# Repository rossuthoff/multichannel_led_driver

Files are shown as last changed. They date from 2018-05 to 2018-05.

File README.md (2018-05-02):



# multichannel_led_driver
Switching boost LED driver based on the Linear Technology [LT3478-1](http://www.analog.com/en/products/power-management/led-driver-ic/buck-boost-led-drivers/lt3478.html) chip.

## related repositories
This design requires the footprints found in the [kicad_footprints](https://github.com/rossuthoff/kicad_footprints) repository. Make sure the library and .mod files are added to your folder search locations. This board utilizes the [ytai/IOIO](https://github.com/ytai/ioio) microcontroller (MCU) and is designed to match to its header layout. Other microcontrollers that can send 3.3 V signals and control an I2C interface may be used. 

## general use
### power supply
LED driver is used in boost mode. The battery voltage must be less than the voltage drop across each individual LED string. Header connnection between this board and the IOIO board provide power to the MCU.

### led strings
Connect the LED strings to V+ (anode) and V1 through V9 (cathodes) connections. The LED string to be illuminated is controlled through a 3.3V signal to the s1 through s9 pins. The applied current is controlled through a Analog Devices [AD5247](http://www.analog.com/en/products/digital-to-analog-converters/digital-potentiometers/ad5247.html) digital potentiometer with an I2C interface.

# references

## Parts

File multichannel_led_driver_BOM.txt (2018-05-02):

Reference	Locations	Value	Footprint	Notes	Manufacturer	PN	Distributor	Dist PN	Dist Link
C1	1	3.3uF	Capacitors_SMD:C_0603	25V	TDK Corporation	C1608X5R1E335K080AC	Digikey	445-14141-1-ND	https://www.digikey.com/product-detail/en/tdk-corporation/C1608X5R1E335K080AC/445-14141-1-ND/3955807
C2	1	4.7uF	Capacitors_SMD:C_1206	25V	TDK Corporation	C3216X5R1E475K160AA	Digikey	445-4047-2-ND	http://www.digikey.com/product-detail/en/tdk-corporation/C3216X5R1E475K160AA/445-4047-2-ND/1965635
C3	1	10uF	Capacitors_SMD:C_1812	25V	TDK Corporation	C4532X5R1E106M250KA	Digikey	445-3926-2-ND	http://www.digikey.com/product-detail/en/tdk-corporation/C4532X5R1E106M250KA/445-3926-2-ND/1923415
"C4, C6"	2	1uF	Capacitors_SMD:C_0603	25V	TDK Corporation	CGB3B1X5R1E105K055AC	Digikey	445-13224-2-ND	http://www.digikey.com/product-detail/en/tdk-corporation/CGB3B1X5R1E105K055AC/445-13224-2-ND/3950460
"C5, C7"	2	0.1uF	Capacitors_SMD:C_0603	25V	Kemet	C0603C104K3RACTU	Digikey	399-1281-1-ND	https://www.digikey.com/product-detail/en/kemet/C0603C104K3RACTU/399-1281-1-ND/416057
C8	1	10uF	Capacitors_Tantalum_SMD:CP_Tantalum_Case-A_EIA-3216-18_Reflow	10V	AVX Corporation	TPSA106K010R0900	Digikey	478-1751-1-ND	https://www.digikey.com/product-detail/en/avx-corporation/TPSA106K010R0900/478-1751-1-ND/564783
D1	1	D_Schottky_AAK	footprints:D_PowerDI-5		Diode Incorporated	PDS560-13	Digikey	PDS560DICT-ND	http://www.digikey.com/product-detail/en/diodes-incorporated/PDS560-13/PDS560DICT-ND/776779
D2	1	LED	footprints:LED_0603		Panasonic Electric Components	LNJ937W8CRA	Digikey	LNJ937W8CRATR-ND	http://www.digikey.com/product-detail/en/panasonic-electronic-components/LNJ937W8CRA/LNJ937W8CRACT-ND/2349027
J1	1	CONN_01X04	JST_PH_S4B-PH-SM4-TB_04x2.00mm_Angled		JST Sales America	S4B-PH-SM4-TB(LF)(SN)	Digikey	455-1751-2-ND	https://www.digikey.com/product-detail/en/jst-sales-america-inc/S4B-PH-SM4-TB-LF-SN/455-1751-2-ND/926657
J4	1	CONN_01X02	Connectors_JST:JST_PH_S2B-PH-SM4-TB_02x2.00mm_Angled		JST Sales America	S2B-PH-SM4-TB(LF)(SN)	Digikey	455-1749-2-ND	http://www.digikey.com/product-detail/en/jst-sales-america-inc/S2B-PH-SM4-TB(LF)(SN)/455-1749-2-ND/926655
L1	1	6.8uH	footprints:Sumida_L_CDRH105R		Sumida America Components	CDRH105RNP-6R8NC	Digikey	308-1927-2-ND	https://www.digikey.com/product-detail/en/sumida-america-components-inc/CDRH105RNP-6R8NC/308-1927-2-ND/3947171
P2	1	CONN_01X06	Connectors_JST:JST_PH_S6B-PH-SM4-TB_06x2.00mm_Angled		JST Sales America	S6B-PH-SM4-TB(LF)(SN)	Digikey	455-1753-2-ND	https://www.digikey.com/product-detail/en/jst-sales-america-inc/S6B-PH-SM4-TB-LF-SN/455-1753-2-ND/926659
"P3,P5,P9,P10,P11,P12,P13,P14,P15,P16"	10		Pin_Headers:Pin_Header_Straight_Pitch2.54mm	DNI					
"Q1,Q2,Q3,Q4,Q9,Q10,Q11,Q12,Q17"	9	Si2308CDS	TO_SOT_Packages_SMD:SOT-23		Vishay Siliconix	SI2308CDS-T1-GE3	Digikey	SI2308CDS-T1-GE3CT-ND	https://www.digikey.com/product-detail/en/vishay-siliconix/SI2308CDS-T1-GE3/SI2308CDS-T1-GE3CT-ND/7616363
"Q5,Q6,Q7,Q8,Q13,Q14,Q15,Q16,Q20"	9	Si2309CDS	TO_SOT_Packages_SMD:SOT-23		Vishay Siliconix	SI2309CDS-T1-GE3	Digikey	SI2309CDS-T1-GE3CT-ND	https://www.digikey.com/product-detail/en/vishay-siliconix/SI2309CDS-T1-GE3/SI2309CDS-T1-GE3CT-ND/3305365
R1	1	100k	Resistors_SMD:R_0402	1%	Yageo	RC0402FR-07100KL	Digikey	311-100KLRTR-ND	http://www.digikey.com/product-detail/en/yageo/RC0402FR-07100KL/311-100KLRTR-ND/726526
R2	1	24k	Resistors_SMD:R_0402	1%	Yageo	RC0402FR-0724KL	Digikey	311-24KLRTR-ND	http://www.digikey.com/product-detail/en/yageo/RC0402FR-0724KL/311-24KLRTR-ND/2827581
R3	1	69.8k	Resistors_SMD:R_0402	1%	Yageo	RC0402FR-0769K8L	Digikey	YAG3216TR-ND	http://www.digikey.com/product-detail/en/yageo/RC0402FR-0769K8L/YAG3216TR-ND/5281076
"R4, R5, R7, R8, R9, R10, R11, R12, R13, R14, R16"	11	10k	Resistors_SMD:R_0603	1%	Yageo	RC0603FR-0710KL	Digikey	311-10.0KHRTR-ND	https://www.digikey.com/product-detail/en/yageo/RC0603FR-0710KL/311-10.0KHRTR-ND/726880
R6	1	1k	Resistors_SMD:R_0603	1%	Yageo	RC0603FR-071KL	Digikey	311-1.00KHRTR-ND	https://www.digikey.com/product-detail/en/yageo/RC0603FR-071KL/311-1.00KHRTR-ND/726843
"R17,R19,R20,R21,R22,R23,R24,R25,R26,R27,R28,R29,R30,R31,R32,R33,R34,R35"	18	510	Resistors_SMD:R_0603	1%	Yageo	RC0603FR-07510RL	Digikey	311-510HRTR-ND	https://www.digikey.com/product-detail/en/yageo/RC0603FR-07510RL/311-510HRTR-ND/727285
SW1	1	SW_SPST	footprints:C&K_SPST_switch_L101011MS02Q		C&K	L101011MS02Q	Digikey	CKC5106-ND	http://www.digikey.com/product-detail/en/c-k/L101011MS02Q/CKC5106-ND/484142
U1	1	LT3478-1	footprints:TSSOP-16-1EP_4.4x5mm_Pitch0.65mm		Linear Technologies	LT3478EFE-1#PBF	Digikey	LT3478EFE-1#PBF-ND	http://www.digikey.com/product-detail/en/linear-technology/LT3478EFE-1-PBF/LT3478EFE-1-PBF-ND/1619965
U3	1	AD5247	footprints:SC-70-6		Analog Devices	AD5247BKSZ10-RL7	Digikey	AD5247BKSZ10-RL7CT-ND	https://www.digikey.com/product-detail/en/analog-devices-inc/AD5247BKSZ10-RL7/AD5247BKSZ10-RL7CT-ND/1140637

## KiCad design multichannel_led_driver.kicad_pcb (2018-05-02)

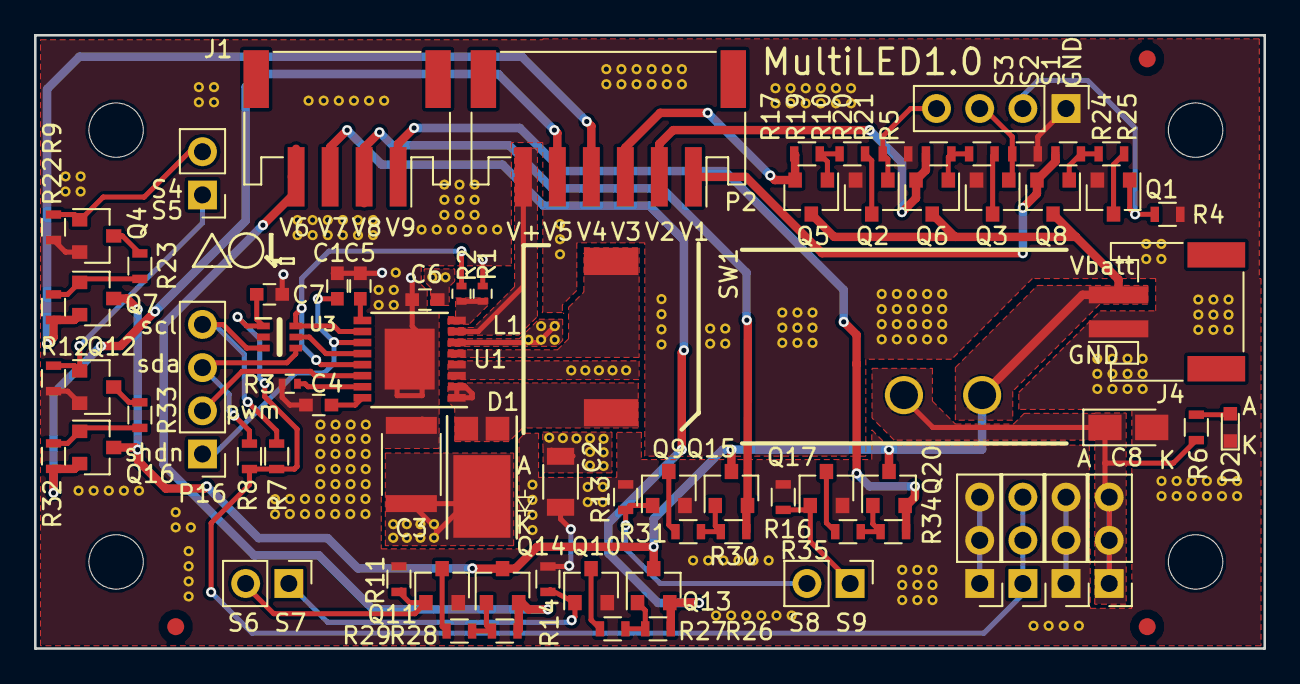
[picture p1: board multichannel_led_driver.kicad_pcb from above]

Board: 2 copper layers, 72.3 x 36.1 mm, 69 parts (0 on the bottom side), 55 nets.

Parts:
C1: 3.3uF; C_0603
C2: 4.7uF; C_1206
C3: 10uF; C_1812
C4, C6: 1uF; C_0603
C5, C7: 0.1uF; C_0603
C8: 10u; CP_Tantalum_Case-A_EIA-3216-18_Reflow
D1: D_Schottky_AAK; D_PowerDI-5
D2: LED; LED_0603
J1: CONN_01X04; JST_PH_S4B-PH-SM4-TB_04x2.00mm_Angled
J4: CONN_01X02; JST_PH_S2B-PH-SM4-TB_02x2.00mm_Angled
L1: 6.8uH; Sumida_L_CDRH105R
P2: CONN_01X06; JST_PH_S6B-PH-SM4-TB_06x2.00mm_Angled
P16: CONN_01X04; Pin_Header_Straight_1x04_Pitch2.54mm
Q1, Q2, Q3, Q4, Q9, Q10, Q11, Q12, Q17: Si2312CDS; SOT-23
Q5, Q6, Q7, Q8, Q13, Q14, Q15, Q16, Q20: Si2315BDS; SOT-23
R1: 100k; R_0402
R2: 24k; R_0402
R3: 69.8k; R_0402
R4, R5, R7, R8, R9, R10, R11, R12, R13, R14, R16: 10k; R_0603
R6: 1k; R_0603
R17, R19, R20, R21, R22, R23, R24, R25, R26, R27, R28, R29, R30, R31, R32, R33, R34, R35: 510; R_0603
SW1: SW_SPST; C&K_SPST_switch_L101011MS02Q
U1: LT3478-1; TSSOP-16-1EP_4.4x5mm_Pitch0.65mm
U3: AD5247; SC-70-6

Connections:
/R_t: R3.2, U1.15
/S1: Q1.1, R4.1
/S2: Q3.1, R5.1
/S3: Q2.1, R10.1
/S4: Q4.1, R9.1
/S5: Q12.1, R12.1
/S6: Q11.1, R11.1
/S7: Q10.1, R14.1
/S8: Q9.1, R13.1
/S9: Q17.1, R16.1
/SCL: P16.4, R7.1, U3.3
/SDA: P16.3, R8.1, U3.4
/SHDN: C1.1, P16.1, U1.11
/SS: C4.1, U1.16
/SW: D1.1, D1.2, L1.1, U1.1, U1.2
/V1-: P2.1, Q8.2, R24.1
/V2-: P2.2, Q6.2, R20.1
/V3-: P2.3, Q5.2, R17.1
/V4-: P2.4, Q7.2, R22.1
/V5-: P2.5, Q16.2, R32.1
/V6-: J1.4, Q14.2, R28.1
/V7-: J1.3, Q13.2, R26.1
/V8-: J1.2, Q15.2, R30.1
/V9-: J1.1, Q20.2, R34.1
/V+: P2.6, U1.7
/V_batt: J4.2, Q5.3, Q6.3, Q7.3, Q8.3, Q13.3, Q14.3, Q15.3, Q16.3, Q20.3, SW1.1
/V_c: C5.1, U1.9
/V_dp: C7.1, R7.2, R8.2, U3.1
/V_io: C2.1, C6.1, C8.1, R6.2, SW1.2, U1.3, U1.4
/V_ref: R2.1, U1.10, U1.13, U3.6
/ctrl1: U1.12, U3.5
/induc: L1.2, U1.5
/ovpset: R1.1, R2.2, U1.8
/pwm: P16.2, U1.14
/v_out: C3.1, D1.3, U1.6
GND: C1.2, C2.2, C3.2, C4.2, C5.2, C6.2, C7.2, C8.2, D2.1, J4.1, Q1.2, Q2.2, Q3.2, Q4.2, Q9.2, Q10.2, Q11.2, Q12.2, Q17.2, R1.2, R3.1, R4.2, R5.2, R9.2, R10.2, R11.2, R12.2, R13.2, R14.2, R16.2, U1.17, U3.2
unnamed: D2.2, R6.1
unnamed: Q1.3, R25.2
unnamed: Q2.3, R19.2
unnamed: Q3.3, R21.2
unnamed: Q4.3, R23.2
unnamed: Q5.1, R17.2, R19.1
unnamed: Q6.1, R20.2, R21.1
unnamed: Q7.1, R22.2, R23.1
unnamed: Q8.1, R24.2, R25.1
unnamed: Q9.3, R31.2
unnamed: Q10.3, R27.2
unnamed: Q11.3, R29.2
unnamed: Q12.3, R33.2
unnamed: Q13.1, R26.2, R27.1
unnamed: Q14.1, R28.2, R29.1
unnamed: Q15.1, R30.2, R31.1
unnamed: Q16.1, R32.2, R33.1
unnamed: Q17.3, R35.2
unnamed: Q20.1, R34.2, R35.1
